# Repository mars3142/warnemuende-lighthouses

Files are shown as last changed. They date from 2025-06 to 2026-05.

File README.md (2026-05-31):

| Supported Targets | ESP32 | ESP32-C3 | ESP32-C5 | ESP32-C6 | ESP32-H2 | ESP32-P4 | ESP32-S3 |
| --- | ----- | --- | --- | --- | --- | --- | --- |

# Mole Beacon

You can find more about it on [my wiki](https://wiki.mars3142.dev/project/maerklin/warnemuende/lighthouse/start).

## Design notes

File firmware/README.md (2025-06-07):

| Supported Targets | ESP32 | ESP32-C3 | ESP32-C5 | ESP32-C6 | ESP32-H2 | ESP32-P4 | ESP32-S3 |
| --- | ----- | --- | --- | --- | --- | --- | --- |

# Warnemuende Lighthouse

You can find more about it on [my wiki](https://wiki.mars3142.dev/project/maerklin/warnemuende/lighthouse/start).

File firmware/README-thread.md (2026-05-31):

# Thread Integration — ESP32-H2 Lighthouse

This document describes the Thread network protocol used by the ESP32-H2 lighthouse
firmware and what the ESP32-C6 coordinator must implement to discover and control it.

---

## Architecture

```
ESP32-C6 (Coordinator / Leader)
    │  Thread / IEEE 802.15.4
    └── ESP32-H2 (Lighthouse / Child or Router)
            CoAP server on port 5683
            Resources: /.well-known/core  /beacon  /outdoor  /flicker  /group
```

The H2 is a **Full Thread Device (FTD)** with leader weight 1, so the C6 always wins
leader election. The H2 operates as Child or Router — never Leader.

---

## 1 — Pre-provisioning: device name

Before first flash, write a human-readable name into the H2's NVS. This name is
announced on the Thread network when the device attaches so the C6 can identify it.

```bash
# requires IDF environment: . $IDF_PATH/export.sh
./scripts/set_device_name.sh "Leuchtturm West"

# or via Make
make set-name NAME="Leuchtturm West"
make set-name NAME="Leuchtturm West" PORT=/dev/cu.usbmodem1101
```

The name is stored in NVS namespace `thread`, key `name`. If no name is set the
device uses `"Lighthouse"` as fallback.

---

## 2 — Thread network credentials

Both the H2 and the C6 use a **fixed, pre-provisioned dataset** — there is no runtime
commissioning (no Joiner, no Commissioner). Both sides must be flashed with identical
credentials.

| Parameter | Value | sdkconfig key |
| --- | --- | --- |
| Network name | `MaerklinNet` | `CONFIG_OPENTHREAD_NETWORK_NAME` |
| Channel | `18` | `CONFIG_OPENTHREAD_NETWORK_CHANNEL` |
| PAN ID | `0xBEEF` | `CONFIG_OPENTHREAD_NETWORK_PANID` |
| ExtPAN ID | `dead00beef00cafe` | `CONFIG_OPENTHREAD_NETWORK_EXTPANID`|
| Network key  | `00112233445566778899aabbccddeeff` | `CONFIG_OPENTHREAD_NETWORK_MASTERKEY`|

**First-time flash procedure:**

Both devices must start with clean NVS to avoid stale dataset conflicts:

```bash
idf.py erase-flash flash   # run on C6 first, then H2
```

**Boot order:** Flash and start the C6 first so it forms the network and wins leader
election. The H2 can then boot at any time — simultaneous boot also works because the
H2's leader weight (1) is always lower than the C6's.

**Dataset application logic (H2):** On boot, `thread_task` calls
`otDatasetIsCommissioned()`. If the dataset is already stored (subsequent boots) it
is used as-is. If not (first boot after erase-flash), `apply_fixed_dataset()` writes
the credentials from sdkconfig into the active dataset.

---

## 3 — Device discovery

Once the H2 attaches to the network (`OT_DEVICE_ROLE_CHILD` or
`OT_DEVICE_ROLE_ROUTER`), it sends a single **NON-CONFIRMABLE CoAP POST** to the
mesh-local all-nodes multicast address:

```
Destination : coap://[ff03::1]:5683/announce
Payload     : <device-name>           e.g. "Leuchtturm West"
```

This is sent exactly once per network attachment (`s_announced` flag). If the C6
restarts it must wait for the next H2 reboot to receive the announce again.

**What the C6 must implement:**

```c
otCoapAddResource(instance, &(otCoapResource){
    .mUriPath = "announce",
    .mHandler = on_announce,   // store sender IPv6 + name
    .mContext = instance,
});
otCoapStart(instance, OT_DEFAULT_COAP_PORT);
```

Record the sender's IPv6 address from `msg_info->mPeerAddr` — this is the unicast
address used for all subsequent CoAP communication with that device.

---

## 4 — Capability discovery

After discovery, query the H2 for its available resources:

```
GET coap://[<H2-addr>]:5683/.well-known/core
```

Response (Content-Format 40 — `application/link-format`):

```
</beacon>;rt="maerklin.switch";title="Blinken";sim;obs,
</outdoor>;rt="maerklin.switch";title="Aussenlicht";sim;obs,
</flicker>;rt="maerklin.value";min=0;max=100;step=5;title="Flackern in %";obs,
</group>;rt="maerklin.group";title="Group"
```

| Resource | Type | Semantics | Observable |
| --- | --- | --- | --- |
| `maerklin.switch` | Boolean `"0"`/`"1"` | On/off toggle | yes |
| `maerklin.value` | Integer string | Numeric value within min/max/step constraints | yes |
| `maerklin.group` | — | Group membership management | no |

The `sim` attribute on `/beacon` and `/outdoor` indicates that these resources
participate in simulated lighting (the `sim/on/...` and `sim/off/...` action
namespace on the C6 side).

---

## 5 — Controlling resources

All unicast control requests use **CONFIRMABLE CoAP** to the H2's unicast IPv6
address on port **5683**.

### `/beacon` — rotating lighthouse light

| Method | Observe option | Payload | Response code |
| --- | --- | --- | --- |
| GET | — | — | 2.05 Content, payload `"1"` or `"0"` |
| GET | `0` (register) | — | 2.05 Content + Observe seq + current state |
| GET | `1` (cancel) | — | 2.05 Content |
| PUT | — | `"1"` | 2.04 Changed |
| PUT | — | `"0"` | 2.04 Changed |

Starts **off** on every boot.

### `/outdoor` — outdoor lamp (flickering flame effect)

| Method | Observe option | Payload | Response code |
| --- | --- | --- | --- |
| GET | — | — | 2.05 Content, payload `"1"` or `"0"` |
| GET | `0` (register) | — | 2.05 Content + Observe seq + current state |
| GET | `1` (cancel) | — | 2.05 Content |
| PUT | — | `"1"` | 2.04 Changed |
| PUT | — | `"0"` | 2.04 Changed |

Starts **off** on every boot.

### `/flicker` — flicker intensity

Controls the random-flicker depth of the outdoor lamp as a percentage (0 = no
flicker / steady, 100 = maximum flicker).

| Method | Observe option | Payload | Response code |
| --- | --- | --- | --- |
| GET | — | — | 2.05 Content, payload `"<0–100>"` |
| GET | `0` (register) | — | 2.05 Content + Observe seq + current value |
| GET | `1` (cancel) | — | 2.05 Content |
| PUT | — | `"<0–100>"` (step 5) | 2.04 Changed |

Values above 100 are clamped to 100.

---

## 6 — Observing resources (RFC 7641)

`/beacon`, `/outdoor`, and `/flicker` support CoAP Observe. The C6 registers once
per device; from that point on the H2 pushes a **NON-CONFIRMABLE** notification to
every registered observer whenever the resource state changes.

### Capacity

Each resource holds up to **4 observers** (`MAX_OBSERVERS`). Registration beyond
that limit is silently ignored.

### Re-registration handling

If the same peer registers with a new token (e.g. after a C6 restart), the H2
updates the existing slot in place rather than consuming a new one. This means a
restarted C6 can re-register without exhausting observer slots.

### Registration

```
GET coap://[<H2-addr>]:5683/beacon
Observe: 0
Token: <client-chosen token>
```

The H2 responds with the current state and the current Observe sequence number.
Keep the token — all incoming notifications carry the same token.

### Cancellation

```
GET coap://[<H2-addr>]:5683/beacon
Observe: 1
Token: <same token as registration>
```

Alternatively send a **RST** in response to any incoming notification.

### Notification format

```
NON 2.05 Content
Observe: <monotonic 24-bit seq>
Content-Format: text/plain
Token: <registration token>
Payload: "1" or "0"   (for /flicker: "<integer>")
```

Notifications are NON-CONFIRMABLE. The C6 does not need to ACK them. Observers
are never automatically evicted — the C6 must cancel explicitly when a device goes
away.

### C6 example

```c
void register_observe(otInstance *inst, otIp6Address *h2_addr, const char *resource)
{
    otMessage *msg = otCoapNewMessage(inst, NULL);
    otCoapMessageInit(msg, OT_COAP_TYPE_CONFIRMABLE, OT_COAP_CODE_GET);
    otCoapMessageGenerateToken(msg, OT_COAP_DEFAULT_TOKEN_LENGTH);
    otCoapMessageAppendObserveOption(msg, 0);
    otCoapMessageAppendUriPathOptions(msg, resource);

    otMessageInfo info = {};
    info.mPeerAddr = *h2_addr;
    info.mPeerPort = OT_DEFAULT_COAP_PORT;

    otCoapSendRequest(inst, msg, &info, on_observe_notification, NULL);
}

void on_observe_notification(void *ctx, otMessage *msg,
                             const otMessageInfo *info, otError err)
{
    if (err != OT_ERROR_NONE) return;
    char buf[8] = {};
    otMessageRead(msg, otMessageGetOffset(msg), buf, sizeof(buf) - 1);
    // buf contains "1", "0", or a decimal integer (flicker)
}
```

---

## 7 — Group management

Groups use **IPv6 multicast**. The C6 assigns H2 devices to named groups by telling
each device which multicast address to subscribe to. A group command is then a single
CoAP request sent to the multicast address — all members receive it simultaneously.

### Joining a group

```
PUT coap://[<H2-addr>]:5683/group
Payload: "<multicast-addr>,1"

Example: "ff03::10,1"
```

### Leaving a group

```
PUT coap://[<H2-addr>]:5683/group
Payload: "<multicast-addr>,0"

Example: "ff03::10,0"
```

Response is `2.04 Changed` in both cases (no error response for invalid addresses —
the parse silently fails).

### Sending a group command

```
PUT coap://[ff03::10]:5683/outdoor
Payload: "1"
```

All H2 devices subscribed to `ff03::10` receive the packet and turn on their outdoor
lamp simultaneously.

### Persistence

Group memberships are persisted in NVS (namespace `thread`, key `groups`) as a
semicolon-separated list of IPv6 address strings. On every boot, after the device
attaches to the network, all previously stored memberships are restored via
`otIp6SubscribeMulticastAddress`. The C6 does not need to reassign memberships after
an H2 reboot.

### Recommended group address range

Use addresses in the **mesh-local multicast scope** `ff03::/16`:

| Address | Suggested use |
| --- | --- |
| `ff03::10` | All outdoor lamps |
| `ff03::11` | All beacons |
| `ff03::20` | Scene: harbour lights |

---

## 8 — Status LED

The H2's status LED (driven by `beacon_set_status`) reflects the Thread network state:

| LED state | `beacon_status_t` | Meaning |
| --- | --- | --- |
| Blue blinking (500 ms) | `BEACON_STATUS_SEARCHING` | Detached — waiting for network  |
| Off | `BEACON_STATUS_CONNECTED` | Child or Router — ready |

`BEACON_STATUS_PAIRING` and `BEACON_STATUS_ERROR` are defined but not triggered by
the current Thread stack (they were used by the former Joiner flow).

---

## Summary — C6 implementation checklist

- [ ] Use identical Thread credentials in sdkconfig (`MaerklinNet`, ch 18, PAN `0xBEEF`, …)
- [ ] Erase flash on both devices before first use to clear stale NVS datasets
- [ ] Start C6 first so it wins leader election
- [ ] Listen for CoAP POST on `/announce` → store sender IPv6 + device name
- [ ] On new device: GET `/.well-known/core` → parse resource types and `obs` attribute
- [ ] Control via unicast PUT to `/beacon`, `/outdoor`, `/flicker`
- [ ] After discovery: register as observer (GET + `Observe: 0`) on `/beacon`, `/outdoor`, `/flicker`
- [ ] Handle incoming NON notifications → update device state in C6 model
- [ ] For group commands: PUT to multicast address + resource path
- [ ] Group membership is restored on H2 reboot — no reconciliation required

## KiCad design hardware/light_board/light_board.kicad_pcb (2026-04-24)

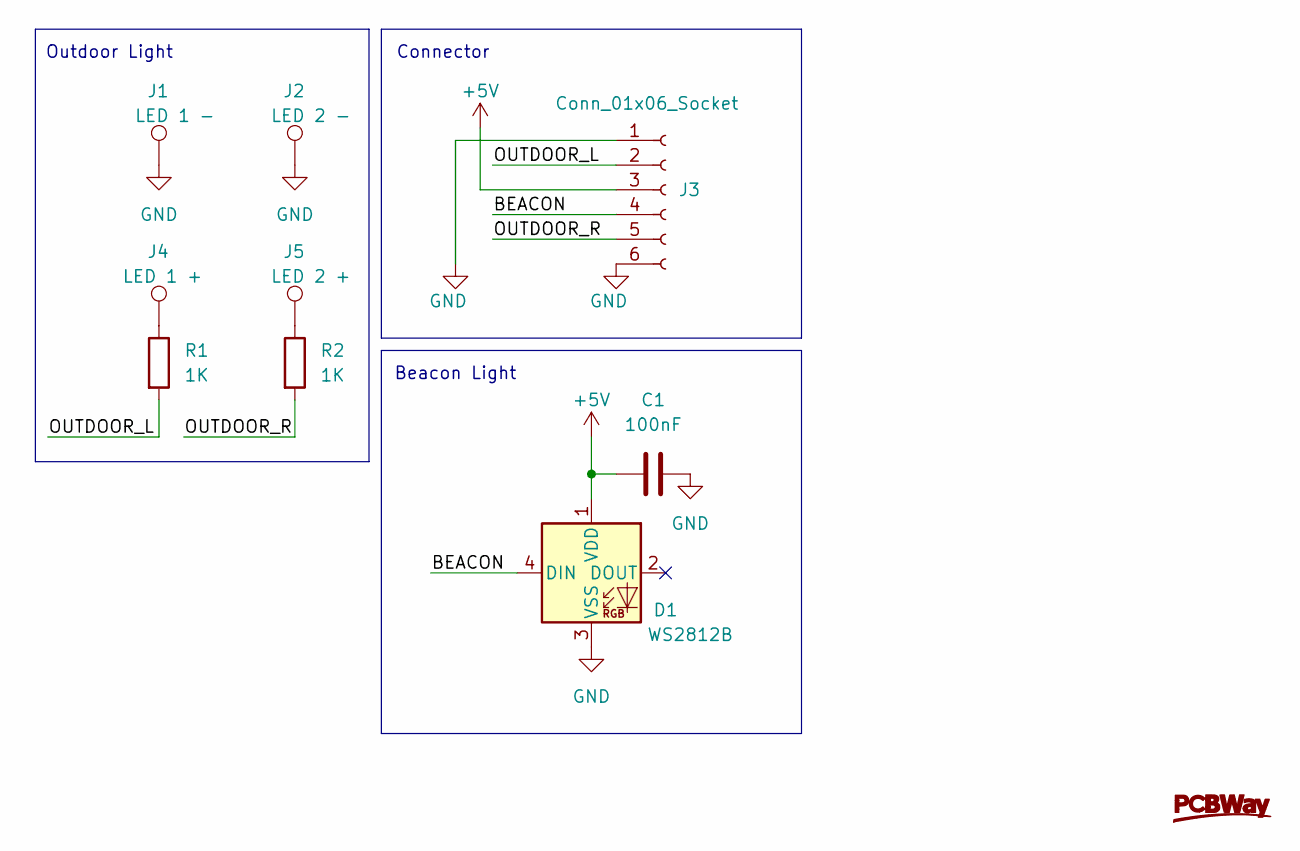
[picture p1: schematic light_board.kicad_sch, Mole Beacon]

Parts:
C1: 100nF; C_0805_2012Metric_Pad1.18x1.45mm_HandSolder
D1: WS2812B; LED_WS2812B_PLCC4_5.0x5.0mm_P3.2mm; MPN 1212; LCSC 511-STM32F405RGT6
J1: LED 1 -; SolderWire-0.1sqmm_1x01_D0.4mm_OD1mm
J2: LED 2 -; SolderWire-0.1sqmm_1x01_D0.4mm_OD1mm
J3: Conn_01x06_Socket; JST_PH_B6B-PH-K_1x06_P2.00mm_Vertical
J4: LED 1 +; SolderWire-0.1sqmm_1x01_D0.4mm_OD1mm
J5: LED 2 +; SolderWire-0.1sqmm_1x01_D0.4mm_OD1mm
R1, R2: 1K; R_0805_2012Metric_Pad1.20x1.40mm_HandSolder

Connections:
+5V: C1.1, D1.1 (VDD), J3.3
/BEACON: D1.4 (DIN), J3.4
/OUTDOOR_L: J3.2, R1.2
/OUTDOOR_R: J3.5, R2.2
GND: C1.2, D1.3 (VSS), J1.1, J2.1, J3.1, J3.6
unnamed: J4.1, R1.1
unnamed: J5.1, R2.1

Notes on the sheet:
Beacon Light
Outdoor Light
Connector

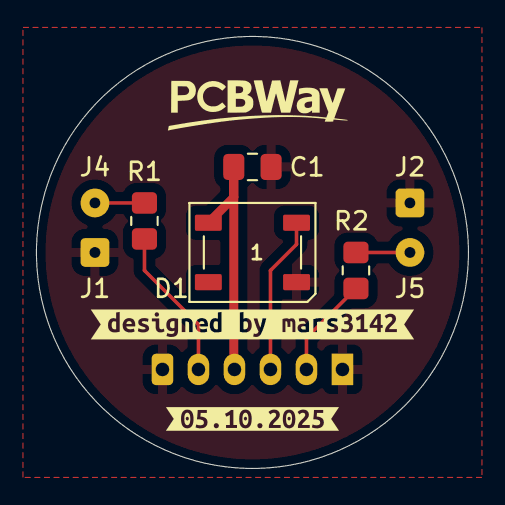
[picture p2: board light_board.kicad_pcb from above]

Board: 2 copper layers, 24.0 x 24.0 mm, 11 parts (1 on the bottom side), 7 nets.

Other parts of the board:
kibuzzard-6876A324: G***; kibuzzard-6876A324
kibuzzard-68711898: G***; kibuzzard-68711898

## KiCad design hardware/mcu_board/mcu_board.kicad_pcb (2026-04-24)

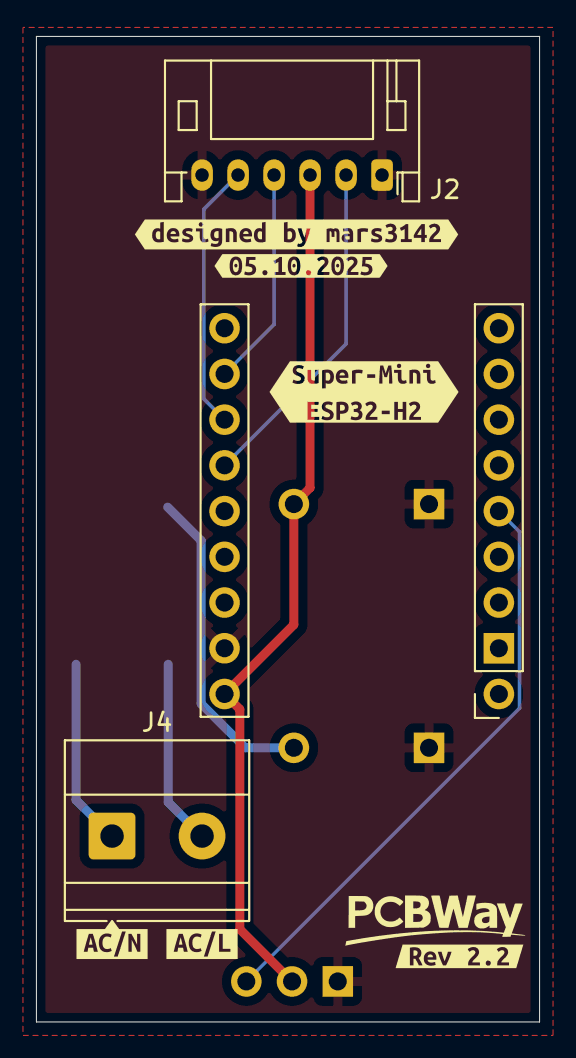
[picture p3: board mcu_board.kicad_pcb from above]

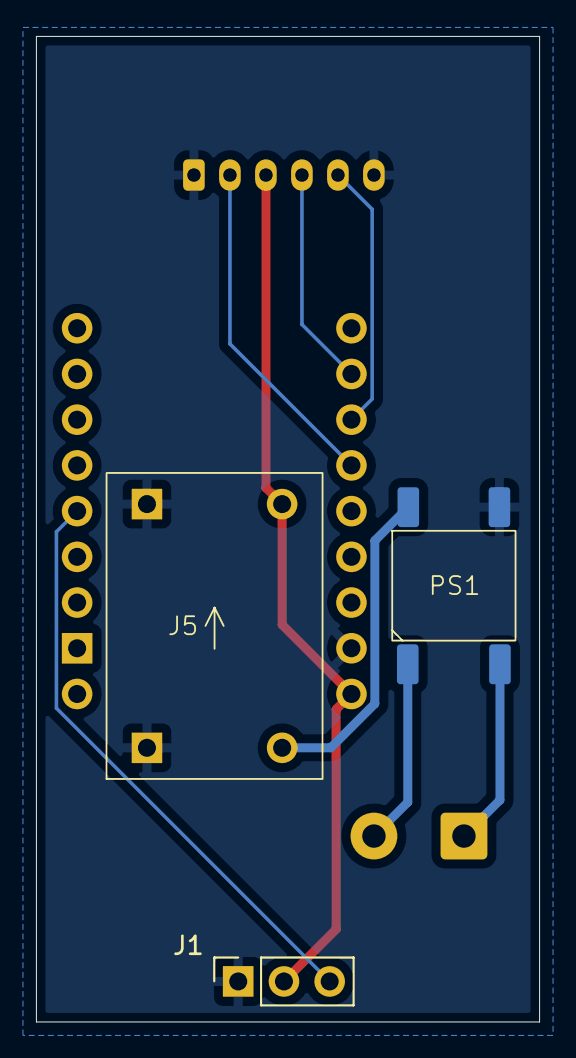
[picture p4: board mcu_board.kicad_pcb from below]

Board: 2 copper layers, 28.0 x 54.8 mm, 12 parts (3 on the bottom side), 9 nets.

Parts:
J1: Touch; PinSocket_1x03_P2.54mm_Vertical
J2: Light; JST_PH_S6B-PH-K_1x06_P2.00mm_Horizontal
J3: Conn_ESP32-H2_Super-Mini_-_Pins_only; PinSocket_H2 Super-Mini
J4: Input; TerminalBlock_Phoenix_MKDS-1,5-2_1x02_P5.00mm_Horizontal
J5: Buck Converter (30V to 5V)
PS1: DB407S
kibuzzard-68F9205C: G***; kibuzzard-68F9205C
kibuzzard-68F9220B: G***; kibuzzard-68F9220B
kibuzzard-68F92064: G***; kibuzzard-68F92064
kibuzzard-689F9361: G***; kibuzzard-689F9361
kibuzzard-6876C4C3: G***; kibuzzard-6876C4C3
kibuzzard-6876C573: G***; kibuzzard-6876C573

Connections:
+5V: J1.2, J2.3, J3.10 (5V), J5.4 (OUT+)
/AC/L: J4.2, PS1.1 (AC/L)
/AC/N: J4.1, PS1.2 (AC/N)
/BEACON: J2.4, J3.17 (GP10)
/IO: J1.3, J3.5 (GP2)
/OUTDOOR_L: J2.2, J3.15 (GP12)
/OUTDOOR_R: J2.5, J3.16 (GP11)
GND: J1.1, J2.1, J2.6, J3.11 (GND), J5.1 (IN-), J5.3 (OUT-), PS1.3 (-Vout)
VCC: J5.2 (IN+), PS1.4 (+Vout)

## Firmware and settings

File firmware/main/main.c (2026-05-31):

#include "esp_event.h"
#include "esp_log.h"
#include "esp_netif.h"
#include "esp_vfs_eventfd.h"
#include "esp_mac.h"

#include "beacon.h"
#include "light.h"
#include "thread_control.h"
#include "persistence.h"
#include "touch.h"

void app_main(void)
{
    uint8_t base_mac[6];
    esp_read_mac(base_mac, ESP_MAC_EFUSE_FACTORY);
    ESP_LOGI("H2", "Factory MAC: %02X:%02X:%02X:%02X:%02X:%02X", 
             base_mac[0], base_mac[1], base_mac[2], base_mac[3], base_mac[4], base_mac[5]);

    ESP_LOGI("H2", "Reset Reason: %d", esp_reset_reason());

    /// init persistence (calls nvs_flash_init internally)
    persistence_init("lighthouse");
    outdoor_init();

    // Required by OpenThread: event loop, netif subsystem, and eventfd VFS
    // (OpenThread task queue uses eventfd internally)
    ESP_ERROR_CHECK(esp_event_loop_create_default());
    ESP_ERROR_CHECK(esp_netif_init());
    esp_vfs_eventfd_config_t eventfd_config = {
        .max_fds = 5,  // Increased for OT task queue, radio driver and potentially others
    };
    ESP_ERROR_CHECK(esp_vfs_eventfd_register(&eventfd_config));

    // init_touch(); // Temporarily disabled for diagnostics

    if (wled_init() != ESP_OK)
    {
        printf("Failed to initialize WLED");
        return;
    }

    if (beacon_init() != ESP_OK)
    {
        printf("Failed to initialize beacon task");
        return;
    }

    if (thread_init() != ESP_OK)
    {
        printf("Failed to initialize thread task");
        return;
    }
}

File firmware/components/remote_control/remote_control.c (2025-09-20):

#include "include/remote_control.h"

#include <stdio.h>
#include <string.h>

#include "esp_event.h"
#include "esp_log.h"
#include "esp_mac.h"
#include "freertos/FreeRTOS.h"
#include "freertos/event_groups.h"
#include "freertos/task.h"
#include "host/ble_hs.h"
#include "host/ble_sm.h"
#include "host/ble_uuid.h"
#include "include/char_desc.h"
#include "include/device_service.h"
#include "include/light_service.h"
#include "include/uart_service.h"
#include "nimble/nimble_port.h"
#include "nimble/nimble_port_freertos.h"
#include "sdkconfig.h"
#include "services/gap/ble_svc_gap.h"
#include "services/gatt/ble_svc_gatt.h"

void ble_store_config_init(void);

static const char *TAG = "remote_control";

static const ble_uuid16_t gatt_svr_svc_device_uuid = BLE_UUID16_INIT(0x180A);
static const ble_uuid16_t gatt_svr_svc_light_uuid = BLE_UUID16_INIT(0xA000);
static const ble_uuid16_t gatt_svr_svc_settings_uuid = BLE_UUID16_INIT(0xA999);

uint8_t ble_addr_type;

ble_connection_t g_connections[CONFIG_BT_NIMBLE_MAX_CONNECTIONS];

static void init_connection_pool()
{
    for (int i = 0; i < CONFIG_BT_NIMBLE_MAX_CONNECTIONS; i++)
    {
        g_connections[i].conn_handle = BLE_HS_CONN_HANDLE_NONE;
        g_connections[i].is_connected = false;
    }
}

bool is_any_device_connected(void)
{
    for (int i = 0; i < CONFIG_BT_NIMBLE_MAX_CONNECTIONS; i++)
    {
        if (g_connections[i].is_connected)
        {
            return true;
        }
    }
    return false;
}

static void ble_app_advertise(void);

// Descriptors for the Beacon Characteristic
static struct ble_gatt_dsc_def beacon_char_desc[] = {
    {
        // User Description Descriptor
        .uuid = BLE_UUID16_DECLARE(0x2901),
        .att_flags = BLE_ATT_F_READ,
        .access_cb = gatt_svr_desc_beacon_user_desc_access,
    },
    {
        // Presentation Format Descriptor
        .uuid = BLE_UUID16_DECLARE(0x2904),
        .att_flags = BLE_ATT_F_READ,
        .access_cb = gatt_svr_desc_presentation_bool_access,
    },
    {
        // Valid Range Descriptor
        .uuid = BLE_UUID16_DECLARE(0x2906),
        .att_flags = BLE_ATT_F_READ,
        .access_cb = gatt_svr_desc_valid_range_bool_access,
    },
    {0},
};

// Descriptors for the LED Characteristic
static struct ble_gatt_dsc_def led_char_desc[] = {
    {
        // User Description Descriptor
        .uuid = BLE_UUID16_DECLARE(0x2901),
        .att_flags = BLE_ATT_F_READ,
        .access_cb = gatt_svr_desc_led_user_desc_access,
    },
    {
        // Presentation Format Descriptor
        .uuid = BLE_UUID16_DECLARE(0x2904),
        .att_flags = BLE_ATT_F_READ,
        .access_cb = gatt_svr_desc_presentation_bool_access,
    },
    {
        // Valid Range Descriptor
        .uuid = BLE_UUID16_DECLARE(0x2906),
        .att_flags = BLE_ATT_F_READ,
        .access_cb = gatt_svr_desc_valid_range_bool_access,
    },
    {0},
};

// Array of pointers to service definitions
static const struct ble_gatt_svc_def gatt_svcs[] = {
    {
        // Device Information Service
        .type = BLE_GATT_SVC_TYPE_PRIMARY,
        .uuid = &gatt_svr_svc_device_uuid.u,
        .characteristics =
            (struct ble_gatt_chr_def[]){
                {
                    // Manufacturer String
                    .uuid = BLE_UUID16_DECLARE(0x2A29),
                    .flags = BLE_GATT_CHR_F_READ,
                    .access_cb = gatt_svr_chr_device_manufacturer_access,
                },
                {
                    // Hardware Revision String
                    .uuid = BLE_UUID16_DECLARE(0x2A27),
                    .flags = BLE_GATT_CHR_F_READ,
                    .access_cb = gatt_svr_chr_device_hardware_access,
                },
                {
                    // Firmware Revision String
                    .uuid = BLE_UUID16_DECLARE(0x2A26),
                    .flags = BLE_GATT_CHR_F_READ,
                    .access_cb = gatt_svr_chr_device_firmware_access,
                },
                {
                    // Device Name
                    .uuid = BLE_UUID16_DECLARE(0x2A00),
                    .flags = BLE_GATT_CHR_F_READ,
                    .access_cb = gatt_svr_chr_device_name_access,
                },
                {0},
            },
    },
    {
        // Light Service
        .type = BLE_GATT_SVC_TYPE_PRIMARY,
        .uuid = &gatt_svr_svc_light_uuid.u,
        .characteristics =
            (struct ble_gatt_chr_def[]){
                {
                    // Beacon Characteristic
                    .uuid = BLE_UUID16_DECLARE(0xBEA0),
                    .flags =
                        BLE_GATT_CHR_F_READ | BLE_GATT_CHR_F_WRITE | BLE_GATT_CHR_F_READ_ENC | BLE_GATT_CHR_F_WRITE_ENC,
                    .access_cb = gatt_svr_chr_light_beacon_access,
                    .descriptors = beacon_char_desc,
                },
                {
                    // LED Characteristic
                    .uuid = BLE_UUID16_DECLARE(0xF037),
                    .flags =
                        BLE_GATT_CHR_F_READ | BLE_GATT_CHR_F_WRITE | BLE_GATT_CHR_F_READ_ENC | BLE_GATT_CHR_F_WRITE_ENC,
                    .access_cb = gatt_svr_chr_light_led_access,
                    .descriptors = led_char_desc,
                },
                {0},
            },
    },
    {
        // UART Service
        .type = BLE_GATT_SVC_TYPE_PRIMARY,
        .uuid = &gatt_svr_svc_uart_uuid.u,
        .characteristics =
            (struct ble_gatt_chr_def[]){
                {
                    // Characteristic: RX (Receiving of data)
                    .uuid = &gatt_svr_chr_uart_rx_uuid.u,
                    .access_cb = gatt_svr_chr_uart_access,
                    .flags = BLE_GATT_CHR_F_WRITE | BLE_GATT_CHR_F_WRITE_NO_RSP,
                },
                {
                    // Characteristic: TX (Sending of data)
                    .uuid = &gatt_svr_chr_uart_tx_uuid.u,
                    .access_cb = gatt_svr_chr_uart_access,
                    .val_handle = &tx_chr_val_handle,
                    .flags = BLE_GATT_CHR_F_NOTIFY,
                },
                {0},
            },
    },
    // Settings Service (empty for now)
    {
        .type = BLE_GATT_SVC_TYPE_PRIMARY,
        .uuid = &gatt_svr_svc_settings_uuid.u,
        .characteristics = (struct ble_gatt_chr_def[]){{0}},
    },
    {0}};

inline static void format_addr(char *addr_str, uint8_t addr[])
{
    sprintf(addr_str, "%02X:%02X:%02X:%02X:%02X:%02X", addr[0], addr[1], addr[2], addr[3], addr[4], addr[5]);
}
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

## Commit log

2025-06-06 empty project
    [partitions.csv]
2025-06-07 led is blinking
2025-06-07 new LED matrix pattern
2025-06-13 Revert "change persistence namespace"
    This reverts commit ef8f6e597e279cafcb5182b5d223cb12ef041ed2.
    [main.c]
2025-08-16 switch to ESP32-H2
2025-08-20 move firmware into subfolder
    [partitions.csv]
2025-08-26 update BLE advertisment
    [partitions.csv]
2025-08-29 try to implement uart over ble
    write is working (print into log), but notify doesn't work yet
    [remote_control.c, uart_service.c]
2025-08-31 add custom PCBs
    [light_board.kicad_pcb, light_board.kicad_sch, mcu_board.kicad_pcb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]
2025-09-01 testing touch interface for physical switching
2025-09-04 latest mcu_board revision
    added buck converter
    [mcu_board.kicad_pcb, mcu_board.kicad_sch]
2025-09-11 add sponsor to PCBs
    [light_board.kicad_pcb, light_board.kicad_sch, mcu_board.kicad_pcb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]
2025-09-16 new mcu board design
    [buck_converter.kicad_sch, mcu_board.kicad_pcb, mcu_board.kicad_sch]
2025-09-20 some tweeks for hardware
    [light_board.kicad_pcb, mcu_board.kicad_pcb]
2025-09-20 add BLE bonding
    [partitions.csv]
2026-04-24 latest KiCad changes
    [light_board.kicad_pcb, light_board.kicad_sch, mcu_board.kicad_pcb]
2026-05-31 .gitea/workflows/esp32_build.yaml aktualisiert
